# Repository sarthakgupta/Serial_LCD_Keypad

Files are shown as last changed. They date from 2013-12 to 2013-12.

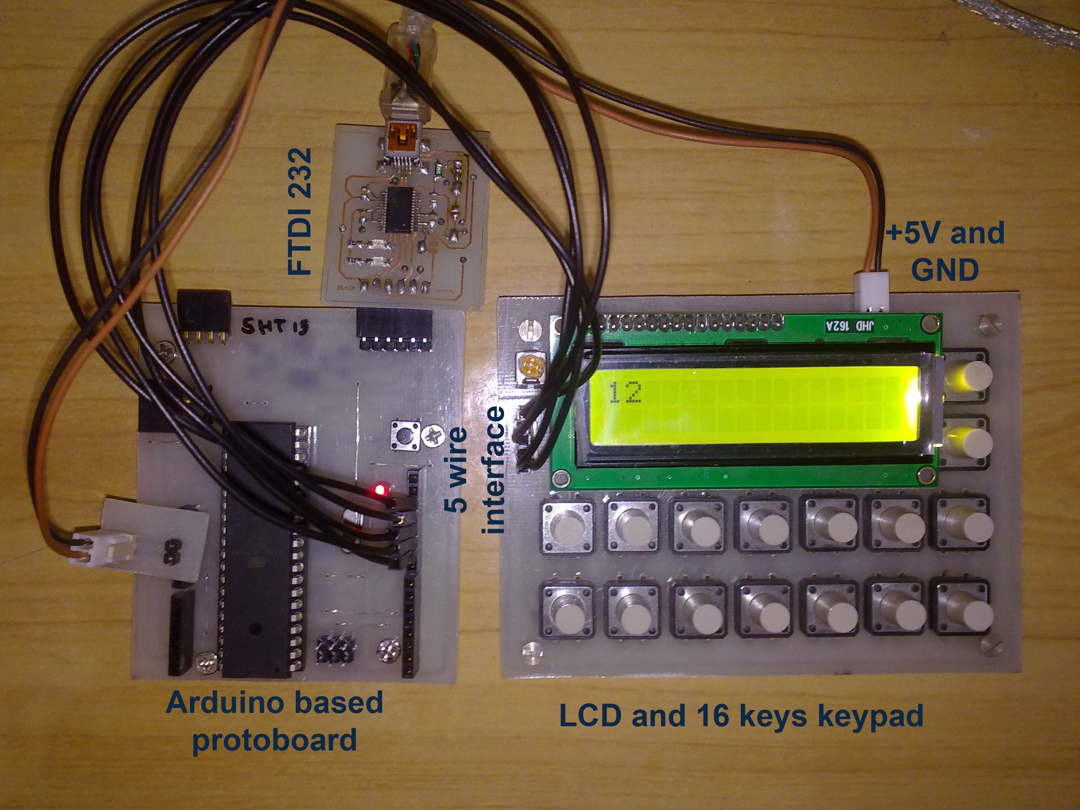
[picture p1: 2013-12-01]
5wire LCD and keypad.jpg

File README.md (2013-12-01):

5 wire interface of LCD and keypad 
==================================

I have used 2 serial 8-bit shift registers(74hct595), which takes serial data, latch clock and serial clock, on giving them 8-bit serial data we can have 8- bit parallel data out of 74hct595, when these two shift registers are placed in cascade manner (you can refer schematic) we can have 16- bit parallel data from 16-bit serial input. I have used keypad in 8x2 format so I need 8 data lines as input to keypad and will be having 2 data lines as output from keypad. When LCD is used in 4-bit mode we need 6 data lines (D4,D5,D6,D7,RS,EN).So I require 3 data lines for shift registers and 2 data lines for keypad, thus 5 data lines to control LCD and Keypad. I have demonstrated it with Arduino Uno and also on the Arduino based protoboard("LOLduino"). It works even if your controller works at 3.3V, because when you give input as 5V to the Vcc of the shift registers, it take 3.3V as high logic.

Cheers!!

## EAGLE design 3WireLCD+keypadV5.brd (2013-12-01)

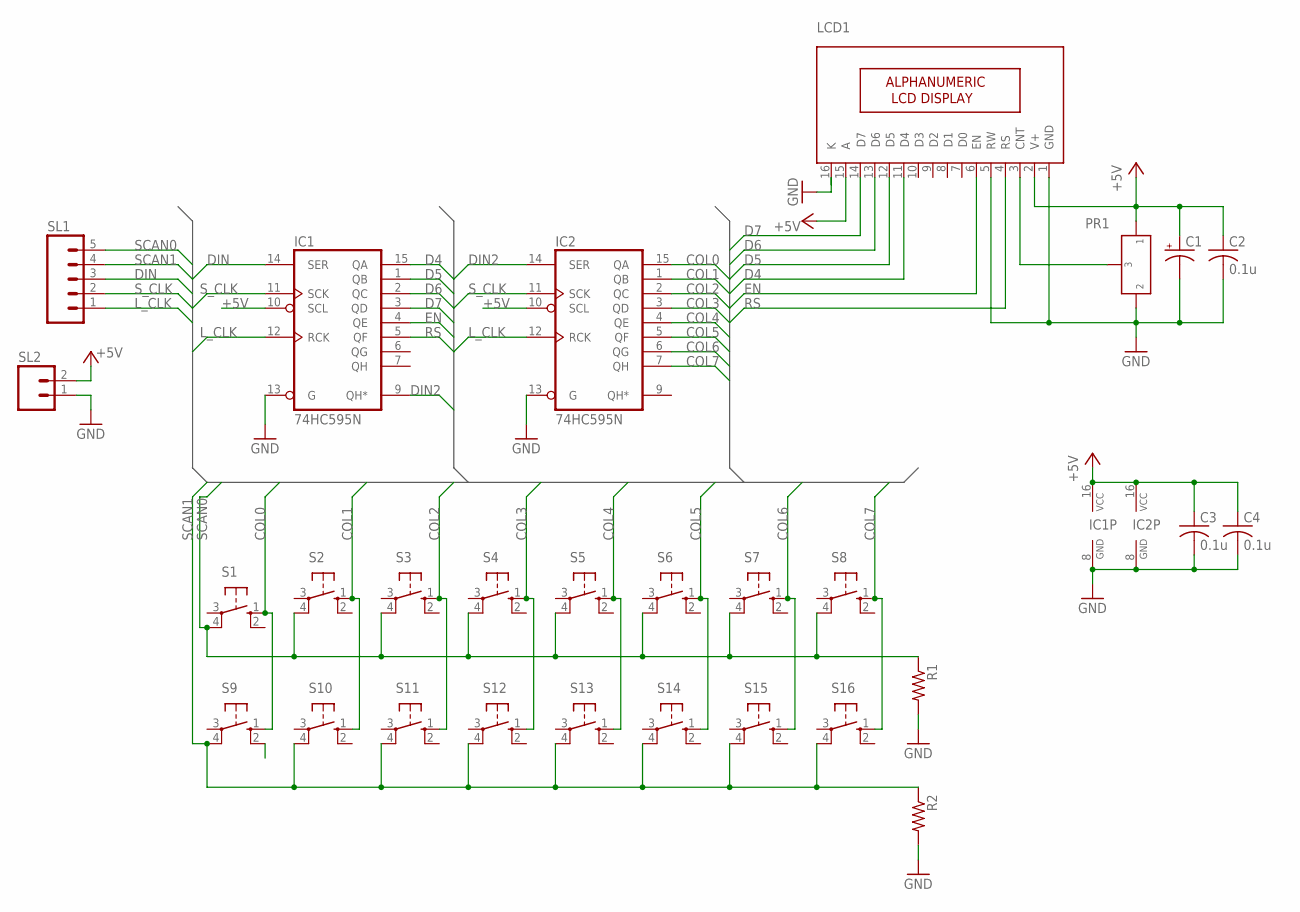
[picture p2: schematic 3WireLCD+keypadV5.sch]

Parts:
C1: CAP_POL_16V; B/3528-21R
C2, C3, C4: 0.1u; C0805
IC1, IC2: 74HC595N; DIL16
LCD1: 16X2LCD; 16X2_LCD
R1, R2: RESISTOR0805; R0805
S1, S2, S3, S4, S5, S6, S7, S8, S9, S10, S11, S12, S13, S14, S15, S16: 40-XX; B3F-40XX
SL1: M05; 05P
SL2: M02; 02P
U$1: PRESET; PRESET_PACK

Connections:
+5V: C1.+, C2.1, C3.1, C4.1, IC1.10 (SCL), IC1.16 (VCC), IC2.10 (SCL), IC2.16 (VCC), LCD1.2 (V+), LCD1.15 (A), SL2.2, U$1.P$1 (1)
COL0: IC2.15 (QA), S1.1 (S), S9.1 (S)
COL1: IC2.1 (QB), S2.1 (S), S10.1 (S)
COL2: IC2.2 (QC), S3.1 (S), S11.1 (S)
COL3: IC2.3 (QD), S4.1 (S), S12.1 (S)
COL4: IC2.4 (QE), S5.1 (S), S13.1 (S)
COL5: IC2.5 (QF), S6.1 (S), S14.1 (S)
COL6: IC2.6 (QG), S7.1 (S), S15.1 (S)
COL7: IC2.7 (QH), S8.1 (S), S16.1 (S)
D4: IC1.15 (QA), LCD1.11 (D4)
D5: IC1.1 (QB), LCD1.12 (D5)
D6: IC1.2 (QC), LCD1.13 (D6)
D7: IC1.3 (QD), LCD1.14 (D7)
DIN: IC1.14 (SER), SL1.3
DIN2: IC1.9 (QH*), IC2.14 (SER)
EN: IC1.4 (QE), LCD1.6 (EN)
GND: C1.-, C2.2, C3.2, C4.2, IC1.8 (GND), IC1.13 (G), IC2.8 (GND), IC2.13 (G), LCD1.1 (GND), LCD1.5 (RW), LCD1.16 (K), R1.2, R2.2, SL2.1, U$1.P$2 (2)
L_CLK: IC1.12 (RCK), IC2.12 (RCK), SL1.1
unnamed: LCD1.3 (CNT), U$1.P$3 (3)
RS: IC1.5 (QF), LCD1.4 (RS)
SCAN0: R1.1, S1.4 (P1), S2.4 (P1), S3.4 (P1), S4.4 (P1), S5.4 (P1), S6.4 (P1), S7.4 (P1), S8.4 (P1), SL1.5
SCAN1: R2.1, S9.4 (P1), S10.4 (P1), S11.4 (P1), S12.4 (P1), S13.4 (P1), S14.4 (P1), S15.4 (P1), S16.4 (P1), SL1.4
S_CLK: IC1.11 (SCK), IC2.11 (SCK), SL1.2

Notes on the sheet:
PR1

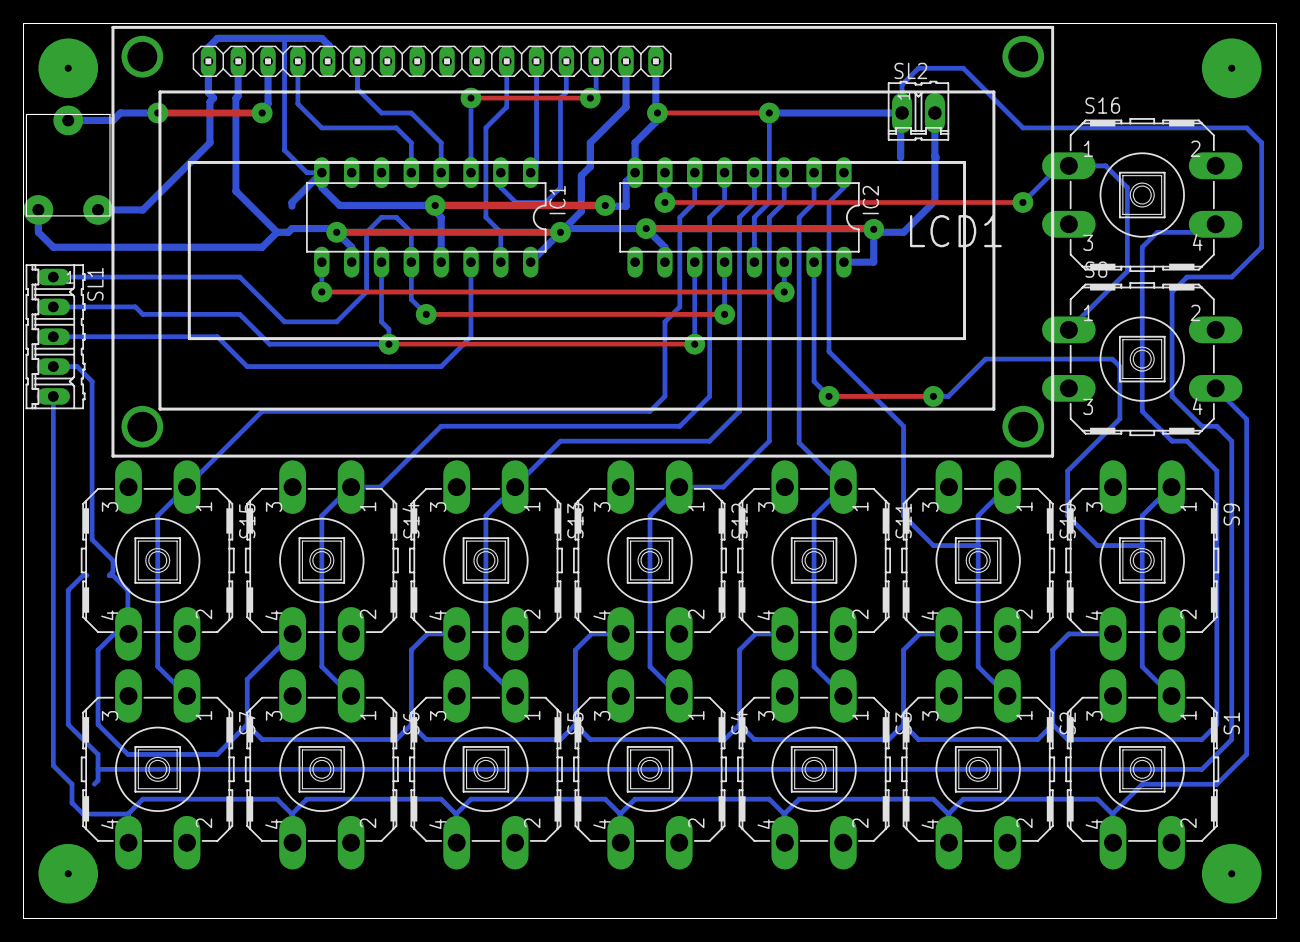
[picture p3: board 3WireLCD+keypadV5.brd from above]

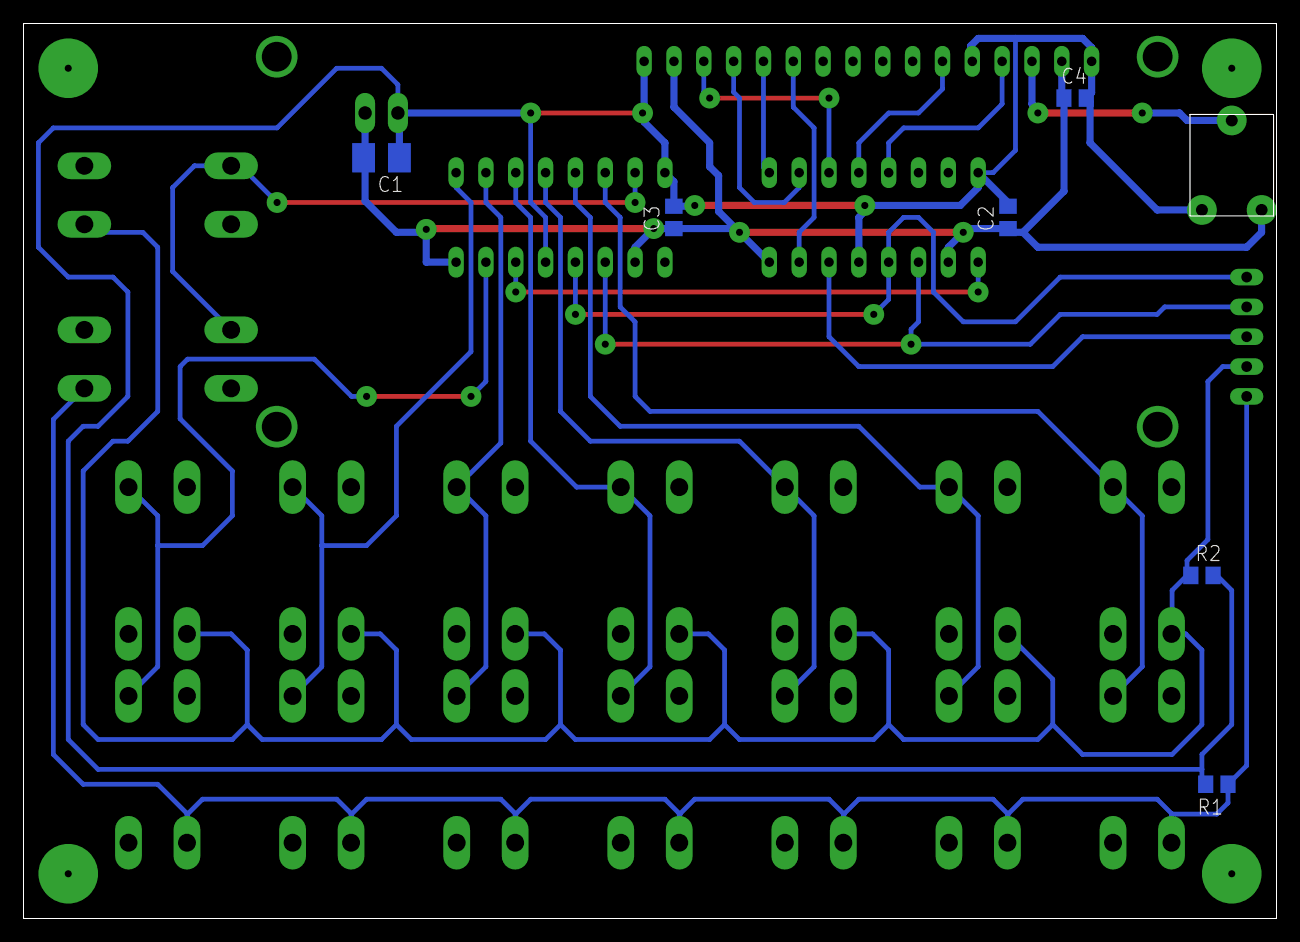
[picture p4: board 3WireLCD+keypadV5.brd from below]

Board: 2 copper layers, 106.7 x 76.2 mm, 28 parts (6 on the bottom side), 23 nets.

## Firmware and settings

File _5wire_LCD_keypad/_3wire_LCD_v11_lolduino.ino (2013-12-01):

int latchPin = 13;
int clockPin = 12;
int dataPin = 11;

void serial_LCD_out(int n1,int n0)
{
    shiftOut(dataPin, clockPin, MSBFIRST, n0);  
    shiftOut(dataPin, clockPin, MSBFIRST, n1+16);  
    digitalWrite(latchPin, HIGH);
    delayMicroseconds(1);
    digitalWrite(latchPin, LOW);
    
    delay(2);
    
    shiftOut(dataPin, clockPin, MSBFIRST, n0);  
    shiftOut(dataPin, clockPin, MSBFIRST, n1);  
    digitalWrite(latchPin, HIGH);
    delayMicroseconds(1);
    digitalWrite(latchPin, LOW);
    //delayMicroseconds(40);
}   

void serial_LCD_out_1(int n1,int n0)
{
    shiftOut(dataPin, clockPin, MSBFIRST, n0);  
    shiftOut(dataPin, clockPin, MSBFIRST, n1);  
    digitalWrite(latchPin, HIGH);
    delayMicroseconds(1);
    digitalWrite(latchPin, LOW);
}   

void print_number(int n)
{   
    serial_LCD_out(35,0);
    serial_LCD_out(32+n,255);
    delayMicroseconds(40); 
}  

void disp_clear()
{
    serial_LCD_out(0,0);
    serial_LCD_out(1,0);
}

void disp_startpoint()
{
    disp_clear();
    serial_LCD_out(8,0);
    serial_LCD_out(0,0);
}

void lcd_init()
{ 
    delay(15);
    serial_LCD_out(3,0);
    delayMicroseconds(4500);
    serial_LCD_out(3,0);
    delayMicroseconds(150);
    
    serial_LCD_out(3,0);
    delayMicroseconds(4500);
    serial_LCD_out(2,0);
    
    //Function Set interface to 4-bit
    serial_LCD_out(2,0);
    serial_LCD_out(8,0);
    
    //Display on
    serial_LCD_out(0,0);
    serial_LCD_out(12,0);
    
    //Display Clear
    serial_LCD_out(0,0);
    serial_LCD_out(1,0);
    
    //Entry Mode Set
    serial_LCD_out(0,0);
    serial_LCD_out(6,0);
  
    //RAM address offset 0x80
    serial_LCD_out(8,0);
    serial_LCD_out(0,0);
}  

void setup() 
{
  //set pins to output so you can control the shift register
  pinMode(latchPin, OUTPUT);
  pinMode(clockPin, OUTPUT);
  pinMode(dataPin, OUTPUT);
  pinMode(10,INPUT);
  pinMode(9,INPUT);
 
  digitalWrite(latchPin, LOW);
  serial_LCD_out(0,0);

  lcd_init();   
  
  //Write #
  serial_LCD_out(34,255);
  serial_LCD_out(35,255);
  delayMicroseconds(40);
  Serial.begin(9600);
    
}

int a = 128;

void loop() 
{
 serial_LCD_out_1(0,255);
 
 //Checking row1(consisting of 8 switches)  
  if(digitalRead(9)==1)
     {
      serial_LCD_out_1(0,1);
      if(digitalRead(9)==1)
         {
         disp_startpoint();
         print_number(1);
         }
      serial_LCD_out_1(0,2);
      if(digitalRead(9)==1)
         {
         disp_startpoint();
         print_number(2);
         }
      serial_LCD_out_1(0,4);
      if(digitalRead(9)==1)
         {
         disp_startpoint();
         print_number(3);
         }
      serial_LCD_out_1(0,8);
      if(digitalRead(9)==1)
         {
         disp_startpoint();
         print_number(4);
         }
      serial_LCD_out_1(0,16);
      if(digitalRead(9)==1)
         {
         disp_startpoint();
         print_number(5);
         }
      serial_LCD_out_1(0,32);
      if(digitalRead(9)==1)
         {
         disp_startpoint();
         print_number(6);
         }
      serial_LCD_out_1(0,64);
      if(digitalRead(9)==1)
         {
         disp_startpoint();
         print_number(7);
         }
      serial_LCD_out_1(0,128);
      if(digitalRead(9)==1)
         {
         disp_startpoint();
         print_number(8);
         }
     }
  //Checking row 2(consisting of 8 switches  
  else if(digitalRead(10)==1)
     {
      serial_LCD_out_1(0,1);
      if(digitalRead(10)==1)
         {
         disp_startpoint();
         print_number(9);
         }
      serial_LCD_out_1(0,2);
      if(digitalRead(10)==1)
         {
         disp_startpoint();
         print_number(1);
         print_number(0);
         }
      serial_LCD_out_1(0,4);
      if(digitalRead(10)==1)
          {
         disp_startpoint();
         print_number(1);
         print_number(1);
         }
      serial_LCD_out_1(0,8);
      if(digitalRead(10)==1)
         {
         disp_startpoint();
         print_number(1);
         print_number(2);
         }
      serial_LCD_out_1(0,16);
      if(digitalRead(10)==1)
         {
         disp_startpoint();
         print_number(1);
         print_number(3);
         }
      serial_LCD_out_1(0,32);
      if(digitalRead(10)==1)
          {
         disp_startpoint();
         print_number(1);
         print_number(4);
         }
      serial_LCD_out_1(0,64);
      if(digitalRead(10)==1)
         {
         disp_startpoint();
         print_number(1);
         print_number(5);
         }
      serial_LCD_out_1(0,128);
      if(digitalRead(10)==1)
        {
          disp_startpoint();
          print_number(1);
          print_number(6);
        }
     }
     
}
